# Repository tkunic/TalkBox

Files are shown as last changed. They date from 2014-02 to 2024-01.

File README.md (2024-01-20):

# TalkBox

The goal of the TalkBox project is to develop an open-source, open-hardware Speech Generating Device (SGD). It provides non-verbal students in special education a way to build a low-cost, easily configurable SGD with the help of their teacher. The TalkBox project has been developed as a collaboration between the [GaMaY Lab](http://gamay.lab.yorku.ca/) at the Lassonde School of Engineering, [Ray Feraday](https://twitter.com/rayferaday) and myself.

Please see [here](https://piet.apps01.yorku.ca/lab-initiative/the-talkbox-project/) for setup instructions and details.

The `mpr121.py` file is derived from Scott Garner's [Beetbox](http://scott.j38.net/interactive/beetbox/) project, which is in turn based on [an Arduino example](http://bildr.org/2011/05/mpr121_arduino/) by Jim Lindblom. The old TalkBox repository can be found [here](https://github.com/hrairhlessil/TalkBox).

## Build one!

You'll need the following materials:

- [MPR121 Capacitive Touch Sensor Breakout Board](https://www.sparkfun.com/products/9695).
- [RaspberryPi](http://www.raspberrypi.org/).
- Some header pins and wires.
- A small speaker.
- As many arts and crafts materials as you like!

## Publications

- [Hamidi, Foad, Melanie Baljko, Toni Kunic, and Ray Feraday. "Do-It-Yourself (DIY) assistive technology: a communication board case study." 14th International Conference, ICCHP, pp. 287-294. Springer, Cham, 2014.](https://link.springer.com/chapter/10.1007%2F978-3-319-08599-9_44)
- [Hamidi, Foad, Melanie Baljko, Toni Kunic, and Ray Feraday. "TalkBox: a DIY communication board case study." Journal of Assistive Technologies 9, no. 4 (2015): 187-198.](http://www.emeraldinsight.com/doi/abs/10.1108/JAT-10-2014-0027)

## Workshops

In collaboration with the [Tetra Society of North America](http://www.tetrasociety.org/), the GaMaY lab conducted a [free workshop](http://talkbox.apps01.yorku.ca/?page_id=4890) at the [2014 Toronto Mini Maker Faire](http://makerfairetoronto.com/), in which we helped children with disabilities make and customize their very own TalkBox.

## Awards

- [2014 Bridge the Gap Award Winner](http://eecs.lassonde.yorku.ca/news/lassonde-talkbox-team-wins-top-prize-at-toronto-maker-faire/).
- [2014 Innovative Designs for Accessibility (IDeA) Competition Finalist](http://www.accessiblecampus.ca/idea/idea-2014/).

## Interviews

- [Interview in Toronto Star](https://www.youtube.com/watch?v=EXKxC0_Ueec)

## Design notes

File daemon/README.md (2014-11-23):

Turn TalkBox into a daemon
==========================

This are instructions to make TalkBox start up when your Pi boots:

Make sure the TalkBox folder is in /home/pi/

Copy the talkbox.sh script into /etc/init.d:

```
sudo cp talkbox.sh /etc/init.d
```

To actually add it to rc.d directories, run:

```
sudo update-rc.d talkbox.sh defaults
```

And you are done!

In case you make modifications to TalkBox, run:
```
sudo /etc/init.d/talkbox.sh stop; sudo /etc/init.d/talkbox.sh start;
```

or just reboot the Pi.

Instructions are based on:
http://blog.scphillips.com/2013/07/getting-a-python-script-to-run-in-the-background-as-a-service-on-boot/

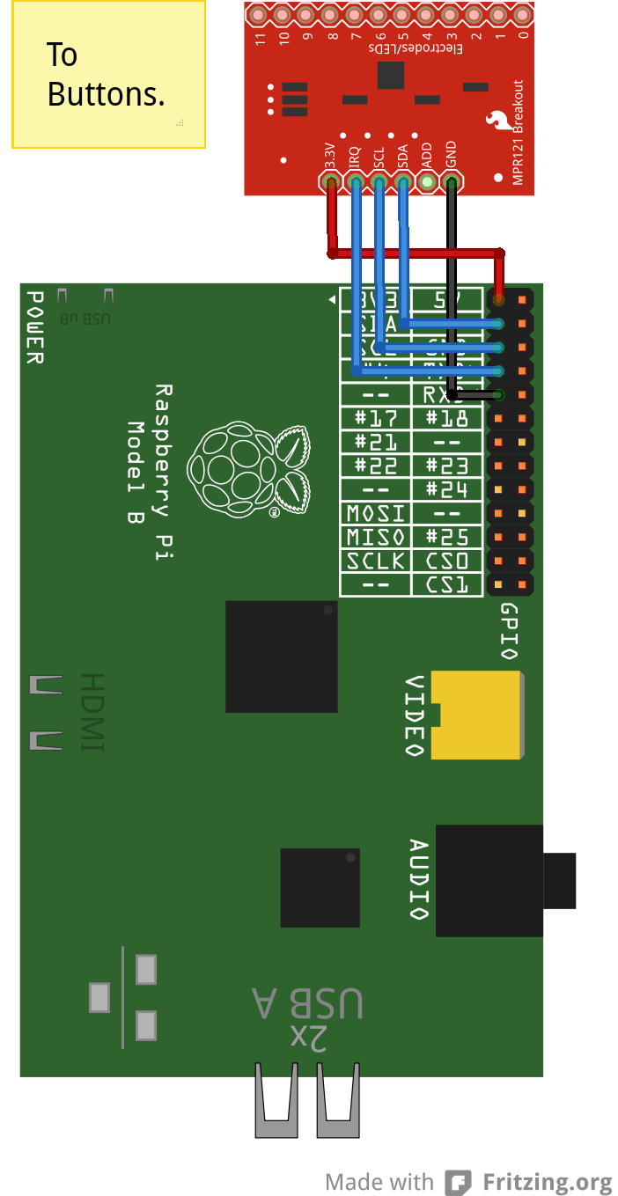
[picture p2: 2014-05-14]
docs/schematic_bb.png

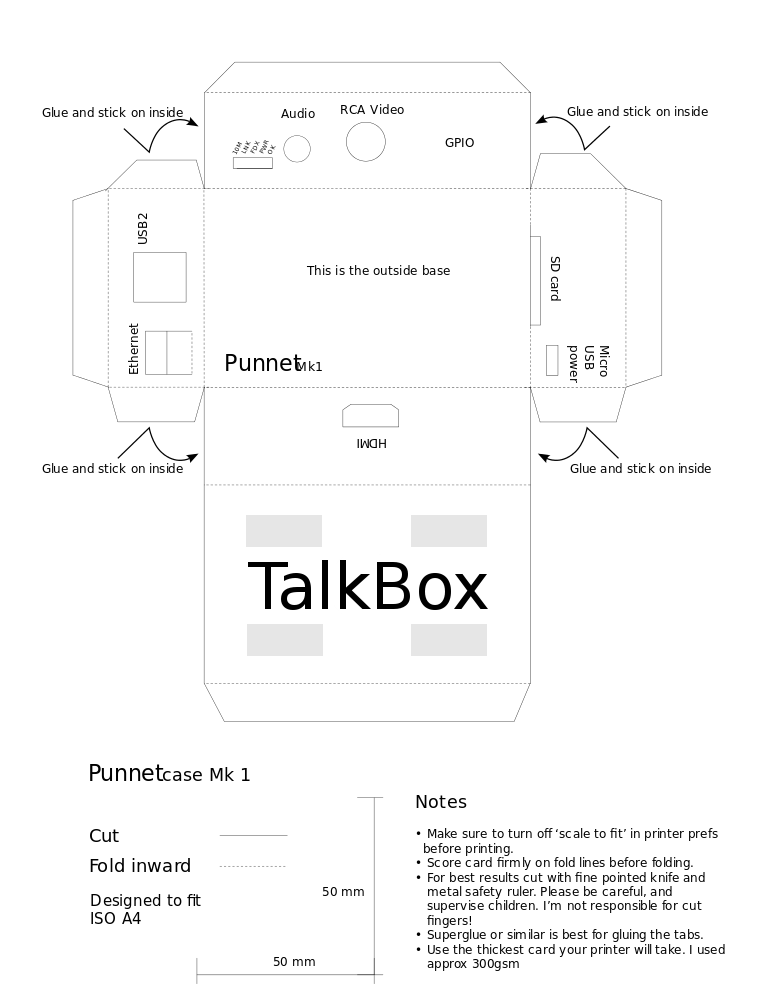
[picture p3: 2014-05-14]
docs/talkbox_case.png

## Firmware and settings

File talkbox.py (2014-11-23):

#!/usr/bin/env python

import logging
import os
import subprocess

import re
import json

import pygame
import web

import RPi.GPIO as GPIO
import mpr121


logging.basicConfig(level=logging.DEBUG,
                    format='[%(levelname)s] (%(threadName)-10s) %(message)s',
                    )

conf_dir = '/home/pi/TalkBox/conf'
num_pins = 12 # FIXME: kinda stuck at 12 due to Upload.POST

class SoundSet():
    """Contains one pin to soundfile mapping."""
    def __init__(self, soundset_dir=os.path.join(conf_dir,'default')):
        self.soundset_dir = soundset_dir
        self.conf_file = os.path.join(soundset_dir, 'conf.json')
        self.conf = {}
        try:
            with open(self.conf_file, 'r') as fin:
                self.conf = json.load(fin)
        except:
            logging.error('Failed to read the conf file at %s' % self.conf_file)
            self.play_sentence("Talk Box failed to load configuration. Please reboot or contact gamay lab.")
            exit(1)

        self.name_file = self.conf['name']
        self.name_sound = self.create_sound(self.name_file)

        self.pins = {}
        for i in xrange(1,num_pins + 1):
            pin_conf = self.conf[str(i)]
            filename = pin_conf['filename']
            self.pins[i] = {}
            self.pins[i]['filename'] = filename
            if filename != "":
                self.pins[i]['sound'] = self.create_sound(filename)
            else:
                self.pins[i]['sound'] = None

        self.play_name()

    def create_sound(self, sound_file):
        sound = pygame.mixer.Sound(sound_file)
        sound.set_volume(1.0)
        return sound

    def get_pin_file(self, pin_num):
        return self.pins[pin_num]['filename']

    def play_pin(self, pin_num):
        sound = self.pins[pin_num]['sound']
        if sound:
            sound.play()
        else:
            logging.warning("Sound not set for pin %d" % pin_num)

    def get_name_file(self):
        return self.name_file

    def play_name(self):
        self.name_sound.play()

    def get_dir(self):
        return self.soundset_dir

    def play_sentence(self, sentence):
        sentence_file = '/tmp/tbsentence.wav'
        subprocess.Popen(['espeak', '"', sentence, '"', '-w', sentence_file], stdout=subprocess.PIPE)
        self.create_sound(sentence_file).play()


class Upload:
    def GET(self):
        global sound_set
        web.header("Content-Type", "text/html; charset=utf-8")

        # TODO: Migrate to web.py templates
        result_list = []
        result_list.append("""<html>
<head>
    <link href="/static/style.css" type="text/css" rel="stylesheet">
</head>
<body>
<img src="static/talkbox_logo.png" id="talkboxlogo">
<form method="POST" enctype="multipart/form-data" action="">\n""")

        for i in xrange(1, num_pins + 1):
            result_list.append("""<div class="pinrow">
    <div class="pinnumber float-left">%d</div>
    <div class="filename float-left">%s</div>
    <div class="uploadbutton float-left">+<input type="file" name="%s" accept="audio/*" /></div>
</div>""" % (i, os.path.basename(sound_set.get_pin_file(i)) if sound_set.get_pin_file(i) != '' else "No File", ''.join(['pinfile', str(i)])))

        result_list.append("""<input type="submit" value="Save" class="savebutton"/>
</form>
</body>
</html>""")
        return ''.join(result_list)

    def POST(self):
        global sound_set
        # TODO: this is silly, but didn't find a better way quickly enough.
        x = web.input(pinfile1={},pinfile2={},pinfile3={},pinfile4={},pinfile5={},pinfile6={},pinfile7={},pinfile8={},pinfile9={},pinfile10={},pinfile11={},pinfile12={})
        for filefield in x.keys():
            # TODO: use os.path for most of this.
            input_filepath = x[filefield].filename.replace('\\', '/')
            input_filename = input_filepath.split('/')[-1]

            # Write the uploaded file to filedir
            file_destination_path = ''
            if input_filename is not None and input_filename != '':
                # TODO: what if someone uploads blap.wav to pin 3 even though it
                # is already on pin 2 and the blap.wav files are different despite
                # the same name? Rename to blap(2).wav.
                file_destination_path = os.path.join(sound_set.get_dir(), input_filename)
                with open(file_destination_path, 'w') as fout:
                    fout.write(x.get(filefield).file.read())
                    fout.close()

            if file_destination_path != '':
                # TODO: this is ugly beyond words. Gets last number in 'pinfileX' string
                pin_num = re.compile('\d+').findall(filefield)[-1]
                self.update_pin_config(pin_num, file_destination_path)

        # FIXME: Ensure no sounds are played while this is being changed.
        sound_set = SoundSet()

        # TODO: Indicate to user that update has been successful.
        raise web.seeother('/')

    def update_pin_config(self, pin_num, file_name):
        # Update the configuration file with the new filenames.
        try:
            conf_file = os.path.join(sound_set.get_dir(), 'conf.json')
            conf = None;

            # Get current contents of config file
            with open(conf_file, 'r') as fin:
                conf = json.load(fin)

            # Write updated config back
            with open(conf_file, 'w') as fout:
                conf[str(pin_num)]['filename'] = file_name
                json.dump(conf, fout, indent=4)

        except Exception as e:
            logging.error("ERROR: failed to write configuration due to: '%s'" % e.message)
            # TODO: actually display this in the browser as feedback to the user
            sound_set.play_sentence("ERROR: failed to write configuration")

class TalkBoxWeb(web.application):
    def run(self, port=8080, *middleware):
        func = self.wsgifunc(*middleware)
        return web.httpserver.runsimple(func, ('0.0.0.0', port))


def handle_touch(channel):
    touchData = mpr121.readWordData(0x5a)
    if not pygame.mixer.get_busy(): # if no sound is playing
        for i in xrange(num_pins):
            if (touchData & (1<<i)):
                sound_set.play_pin(i + 1)


if __name__ == "__main__":
    # Init GPIO Interrupt Pin
    GPIO.setmode(GPIO.BOARD)
    GPIO.setup(7, GPIO.IN, pull_up_down=GPIO.PUD_UP)

    # Init mpr121 touch sensor
    mpr121.TOU_THRESH = 0x30
    mpr121.REL_THRESH = 0x33
    mpr121.setup(0x5a)

    # Init Pygame
    pygame.mixer.pre_init(44100, -16, 12, 512)
    pygame.init()

    # FIXME: shouldn't be global, but short on time
    sound_set = SoundSet()
    # Add callback to pin 7 (interrupt)
    GPIO.add_event_detect(7, GPIO.FALLING, callback=handle_touch)

    # Init Web (which in turn inits buttons)
    # TODO: add further URLs, for example to test I2C and other statuses.
    urls = ('/', 'Upload')
    app = TalkBoxWeb(urls, globals())
    app.run(port=80)

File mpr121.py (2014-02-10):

# Based on Arduino example by Jim Lindblom
# http://bildr.org/2011/05/mpr121_arduino/

import smbus
bus = smbus.SMBus(1)

# MPR121 Register Defines

MHD_R = 0x2B
NHD_R = 0x2C
NCL_R = 0x2D
FDL_R = 0x2E
MHD_F = 0x2F
NHD_F = 0x30
NCL_F = 0x31
FDL_F = 0x32
ELE0_T = 0x41
ELE0_R = 0x42
ELE1_T = 0x43
ELE1_R = 0x44
ELE2_T = 0x45
ELE2_R = 0x46
ELE3_T = 0x47
ELE3_R = 0x48
ELE4_T = 0x49
ELE4_R = 0x4A
ELE5_T = 0x4B
ELE5_R = 0x4C
ELE6_T = 0x4D
ELE6_R = 0x4E
ELE7_T = 0x4F
ELE7_R = 0x50
ELE8_T = 0x51
ELE8_R = 0x52
ELE9_T = 0x53
ELE9_R = 0x54
ELE10_T = 0x55
ELE10_R = 0x56
ELE11_T = 0x57
ELE11_R = 0x58
FIL_CFG = 0x5D
ELE_CFG = 0x5E
GPIO_CTRL0 = 0x73
GPIO_CTRL1 = 0x74
GPIO_DATA = 0x75
GPIO_DIR = 0x76
GPIO_EN = 0x77
GPIO_SET = 0x78
GPIO_CLEAR = 0x79
GPIO_TOGGLE = 0x7A
ATO_CFG0 = 0x7B
ATO_CFGU = 0x7D
ATO_CFGL = 0x7E
ATO_CFGT = 0x7F

# Global Constants

TOU_THRESH = 0x06
REL_THRESH = 0x0A

# Routines

def readData(address):
	MSB = bus.read_byte_data(address, 0x00)
	LSB = bus.read_byte_data(address, 0x01)

	#touchData = (MSB << 8) | LSB
	touchData = MSB;

	return touchData;

def readWordData(address):
        MSB = bus.read_word_data(address, 0x00)
        LSB = bus.read_word_data(address, 0x01)

        #touchData = (MSB << 8) | LSB
        touchData = MSB;

        return touchData;

def setup(address):

	bus.write_byte_data(address, ELE_CFG, 0x00)

	# Section A - Controls filtering when data is > baseline.
	 
	bus.write_byte_data(address, MHD_R, 0x01)
	bus.write_byte_data(address, NHD_R, 0x01)
	bus.write_byte_data(address, NCL_R, 0x00)
	bus.write_byte_data(address, FDL_R, 0x00)

	# Section B - Controls filtering when data is < baseline.

	bus.write_byte_data(address, MHD_F, 0x01)
	bus.write_byte_data(address, NHD_F, 0x01)
	bus.write_byte_data(address, NCL_F, 0xFF)
	bus.write_byte_data(address, FDL_F, 0x02)	

	#Section C - Sets touch and release thresholds for each electrode

	bus.write_byte_data(address, ELE0_T, TOU_THRESH)
	bus.write_byte_data(address, ELE0_R, REL_THRESH)

	bus.write_byte_data(address, ELE1_T, TOU_THRESH)
	bus.write_byte_data(address, ELE1_R, REL_THRESH)

	bus.write_byte_data(address, ELE2_T, TOU_THRESH)
	bus.write_byte_data(address, ELE2_R, REL_THRESH)

	bus.write_byte_data(address, ELE3_T, TOU_THRESH)
	bus.write_byte_data(address, ELE3_R, REL_THRESH)

	bus.write_byte_data(address, ELE4_T, TOU_THRESH)
	bus.write_byte_data(address, ELE4_R, REL_THRESH)

	bus.write_byte_data(address, ELE5_T, TOU_THRESH)
	bus.write_byte_data(address, ELE5_R, REL_THRESH)

	bus.write_byte_data(address, ELE6_T, TOU_THRESH)
	bus.write_byte_data(address, ELE6_R, REL_THRESH)

	bus.write_byte_data(address, ELE7_T, TOU_THRESH)
	bus.write_byte_data(address, ELE7_R, REL_THRESH)

	bus.write_byte_data(address, ELE8_T, TOU_THRESH)
	bus.write_byte_data(address, ELE8_R, REL_THRESH)

	bus.write_byte_data(address, ELE9_T, TOU_THRESH)
	bus.write_byte_data(address, ELE9_R, REL_THRESH)

	bus.write_byte_data(address, ELE10_T, TOU_THRESH)
	bus.write_byte_data(address, ELE10_R, REL_THRESH)

	bus.write_byte_data(address, ELE11_T, TOU_THRESH)
	bus.write_byte_data(address, ELE11_R, REL_THRESH)	

	# Section D
	# Set the Filter Configuration
	# Set ESI2

	bus.write_byte_data(address, FIL_CFG, 0x04)

	# Section E
	# Electrode Configuration
	# Set ELE_CFG to 0x00 to return to standby mode

	bus.write_byte_data(address, ELE_CFG, 0x0C)  # Enables all 12 Electrodes	

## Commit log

2014-04-05 added simplified schematic based on Scott's work
    [schematic.fzz]
2014-05-07 added play button (view only) and file browser
2014-05-10 fixed on_rm_button_clicked for soundset list
    [talkbox.py]
2014-05-11 Removed soundfiles from pin definition with soundstrings. They can represent both strings to be espoken and file paths.
2014-05-11 added espeak to readme and added expected output for i2c config
